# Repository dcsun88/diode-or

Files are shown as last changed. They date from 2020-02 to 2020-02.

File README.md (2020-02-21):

# diode-or
Active and Passive Diode ORing KiCAD Design

The passive or'ing is two parallel 20A 100V shcottky diodes.  The active or'ing uses a 72A 100V N-channel MOSFET and the lm5050-1 or'ing controller.  The binding posts are set up so both paths can be used in parallel or independently.

## Mechanical parts not in the BOM
* 1  Hammond Manufacturing  1591L  box 3.30"Lx2.20"Wx1.40"H
* 4x M3x5mm pan head Phillips screw
* 2x Wakefield-Vette  CD-02-05-247 Or CD-02-05-247-N  TO-247 ulTIMiFlux Dielectric Phase Change Thermal Material
* 1  Pomona  4115  Binding post shorting link
* 5x Binding post connector assembly.
   * 5x TE Connectivity  326854  terminal, ring 14-16AWG  #2 stud
   * 5x TE Connectivity  34123  terminal, ring 14-16AWG  #10 stud
   * 5x McMaster-Carr 69925K67  grounding braid noninsulated, 14 wire gauge equivalent, 20mm length

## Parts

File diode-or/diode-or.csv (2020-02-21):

Reference | Value | Footprint | Datasheet | Manufacturer | PartNum | Power | Tolerance | Dielectric | Voltage | Current
R1 | 100R | local:R_0805_HandSoldering |  | Vishay Dale | CRCW0805100RFKEA | 0.125W | 1%
U1 | LM5050-1 | Package_TO_SOT_SMD:TSOT-23-6 | http://www.ti.com/lit/ds/symlink/lm5050-1-q1.pdf | Texas Instruments | LM5050MKX-1
C2 | 0.1uF | local:C_0805_HandSoldering |  | Kemet | C0805C104K5RACTU |  | 10% | X7R | 50V
D1 | STPS40H100CW | Package_TO_SOT_THT:TO-247-3_Vertical | ~ | STMicro | STPS40H100CW |  |  |  | 100V | 20A
D3 | LL4148 | local:D_MiniMELF-onsemi |  | ON Semiconductor | LL4148 |  |  |  | 100V | 200mA
J1 | Binding Post (RED) | local:Binding_Post_Hex | ~ | Keystone | 7016
J3 | Binding Post (RED) | local:Binding_Post_Hex | ~ | Keystone | 7016
J4 | Binding Post (BLACK) | local:Binding_Post_Hex | ~ | Keystone | 7017
D4 | SS16T3 | Diode_SMD:D_SMA | ~ | ON Semiconductor | SS16T3 |  |  |  | 60V | 1A
D6 | SS16T3 | Diode_SMD:D_SMA | ~ | ON Semiconductor | SS16T3 |  |  |  | 60V | 1A
D2 | SMBJ60A | Diode_SMD:D_SMB | ~ | Littelfuse | SMBJ60A | 5.0W |  |  | 60V
J2 | Binding Post (RED) | local:Binding_Post_Hex | ~ | Keystone | 7016
J5 | Binding Post (BLACK) | local:Binding_Post_Hex | ~ | Keystone | 7017
R2 | 100R | local:R_0805_HandSoldering |  | Vishay Dale | CRCW0805100RFKEA | 0.125W | 1%
D5 | LL4148 | local:D_MiniMELF-onsemi |  | ON Semiconductor | LL4148 |  |  |  | 100V | 200mA
SW1 | SW_SPDT | local:ASE1D-6M-10-Z | ~ | Nidec Copal | ASE1D-2M-10-Z |  |  |  | 60V | 50mA
C3 | 1uF | local:C_1206_HandSoldering |  | Samsung | CL31B105KCHNFNE |  | 10% | X7R | 100V
C1 | 22uF | Capacitor_SMD:CP_Elec_6.3x5.9 |  | Panasonic | EEE-FK1J220XP |  | 20% | Alum | 63V
BT1 | Battery | Connector_PinHeader_2.54mm:PinHeader_1x02_P2.54mm_Vertical | ~ |  |  |  |  |  | 9.0V
Q1 | IRFP4710PBF | Package_TO_SOT_THT:TO-247-3_Vertical | ~ | Infineon | IRFP4710PBF | 190W |  |  | 100V | 72A
D8 | AM2520ZGC09 | local:AM2520ZGC09 | ~ | Kingbright | AM2520ZGC09
D7 | MM3Z3V0T1G | local:SOD-323_477-02-H_HandSoldering | ~ | ON Semiconductor | MM3Z3V0T1G | 300mW |  |  | 3.0V
R3 | 4.99K | local:R_0805_HandSoldering |  | Vishay Dale | CRCW08054K99FKEA | 0.125W | 1%
H1 | MountingHole_Pad | MountingHole:MountingHole_3.2mm_M3_Pad_Via | ~
H3 | MountingHole_Pad | MountingHole:MountingHole_3.2mm_M3_Pad_Via | ~
H2 | MountingHole_Pad | MountingHole:MountingHole_3.2mm_M3_Pad_Via | ~
H4 | MountingHole_Pad | MountingHole:MountingHole_3.2mm_M3_Pad_Via | ~
HS1 | MA-301-27E | local:MA-301-27E | ~ | Ohmite | MA-301-27E
U2 | PSSI2021SAY | Package_TO_SOT_SMD:SOT-353_SC-70-5 | ~ | NXP Semiconductors | PSSI2021SAY

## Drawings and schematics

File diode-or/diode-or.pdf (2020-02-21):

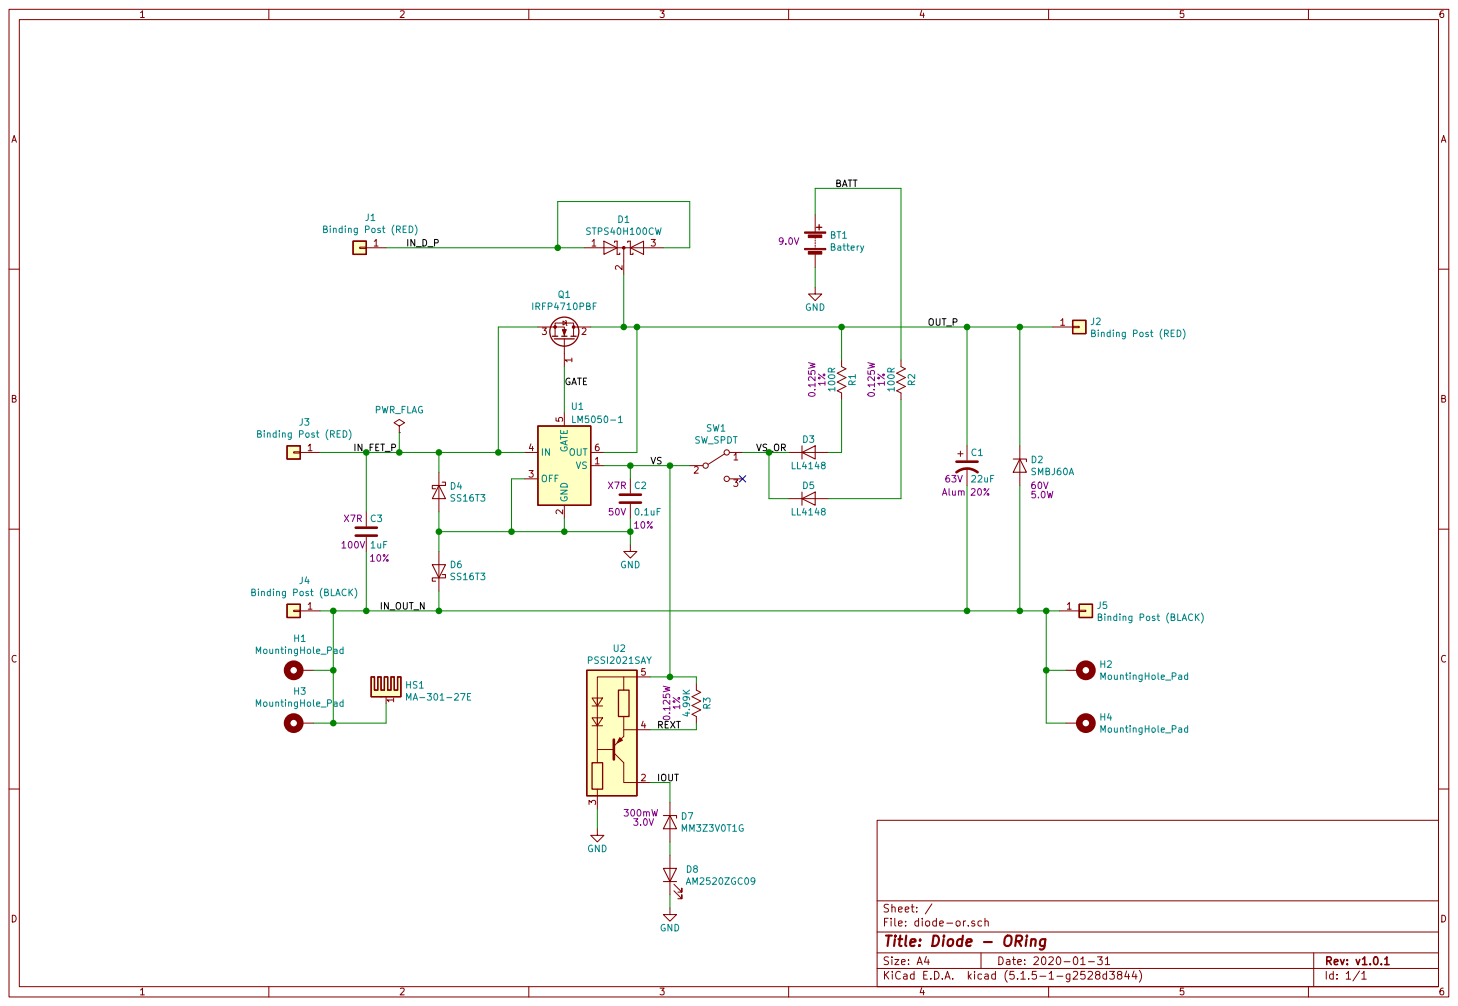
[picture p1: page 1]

File: diode-or.sch Sheet: /
Id: 1/1 Title: Diode - ORing

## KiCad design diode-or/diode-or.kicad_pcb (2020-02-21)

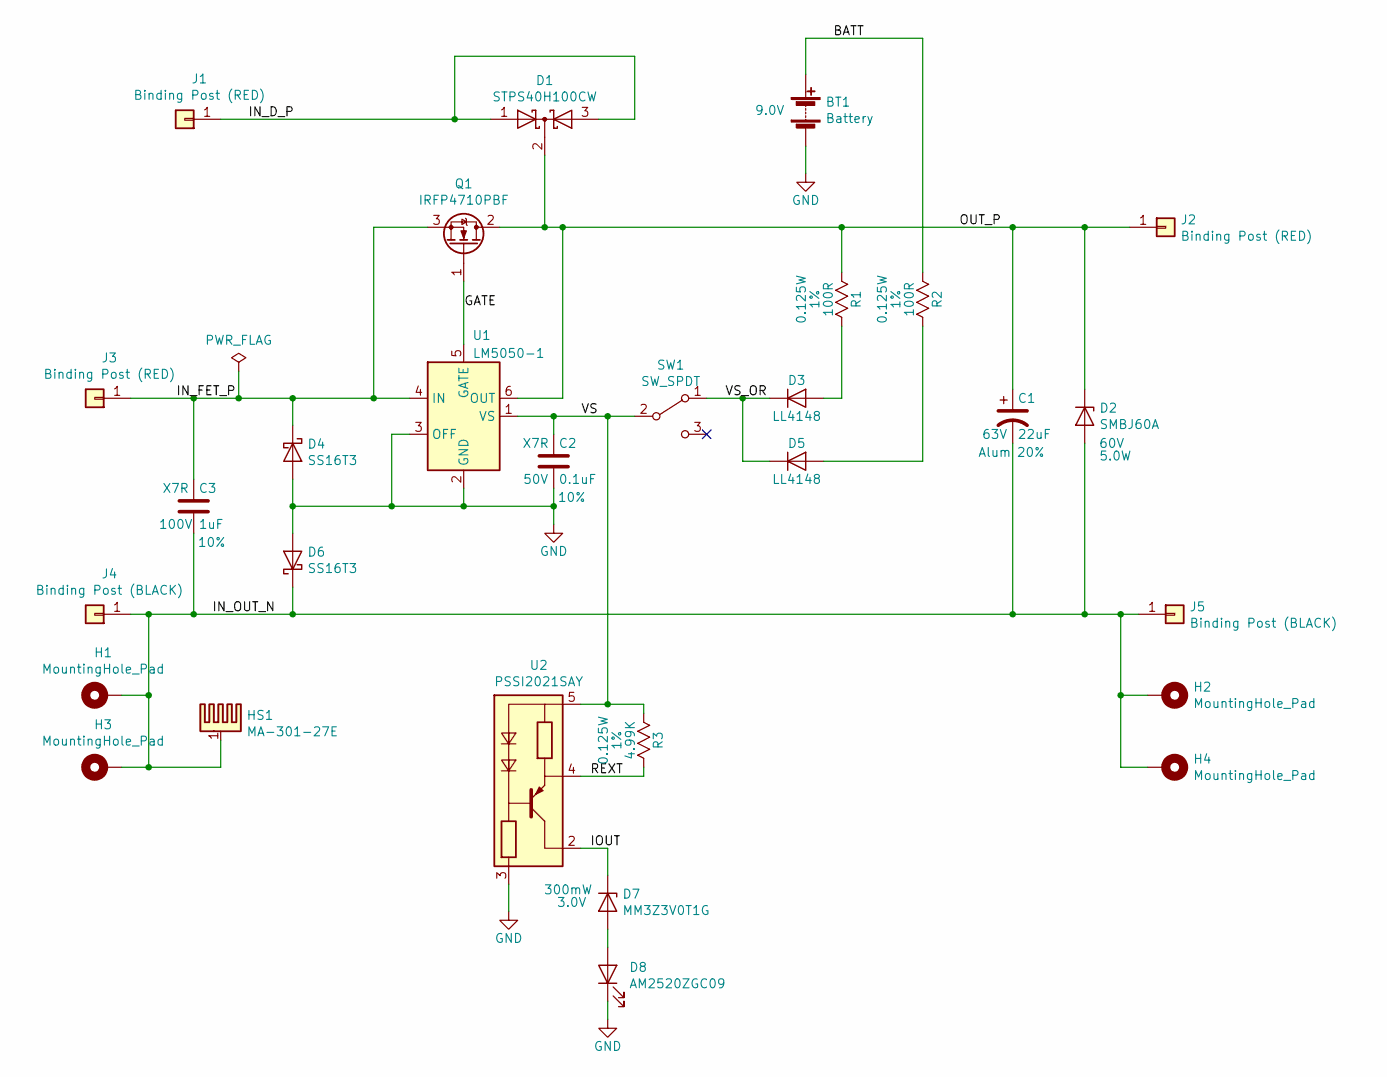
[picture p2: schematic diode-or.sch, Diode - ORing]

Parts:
BT1: Battery; PinHeader_1x02_P2.54mm_Vertical; Voltage 9.0V
C1: 22uF; CP_Elec_6.3x5.9; Voltage 63V; Tolerance 20%; PartNum EEE-FK1J220XP
C2: 0.1uF; C_0805_HandSoldering; Voltage 50V; Tolerance 10%; PartNum C0805C104K5RACTU
C3: 1uF; C_1206_HandSoldering; Voltage 100V; Tolerance 10%; PartNum CL31B105KCHNFNE
D1: STPS40H100CW; TO-247-3_Vertical; Voltage 100V; PartNum STPS40H100CW
D2: SMBJ60A; D_SMB; Voltage 60V; PartNum SMBJ60A
D3, D5: LL4148; D_MiniMELF-onsemi; Voltage 100V; PartNum LL4148
D4, D6: SS16T3; D_SMA; Voltage 60V; PartNum SS16T3
D7: MM3Z3V0T1G; SOD-323_477-02-H_HandSoldering; Voltage 3.0V; PartNum MM3Z3V0T1G
D8: AM2520ZGC09; PartNum AM2520ZGC09
H1, H2, H3, H4: MountingHole_Pad; MountingHole_3.2mm_M3_Pad_Via
HS1: MA-301-27E; PartNum MA-301-27E
J1, J2, J3: Binding Post (RED); Binding_Post_Hex; PartNum 7016
J4, J5: Binding Post (BLACK); Binding_Post_Hex; PartNum 7017
Q1: IRFP4710PBF; TO-247-3_Vertical; Voltage 100V; PartNum IRFP4710PBF
R1, R2: 100R; R_0805_HandSoldering; Tolerance 1%; PartNum CRCW0805100RFKEA
R3: 4.99K; R_0805_HandSoldering; Tolerance 1%; PartNum CRCW08054K99FKEA
SW1: SW_SPDT; ASE1D-6M-10-Z; Voltage 60V; PartNum ASE1D-2M-10-Z
U1: LM5050-1; TSOT-23-6; PartNum LM5050MKX-1
U2: PSSI2021SAY; SOT-353_SC-70-5; PartNum PSSI2021SAY

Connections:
/BATT: BT1.1 (+), R2.1
/GATE: Q1.1 (G), U1.5 (GATE)
/IN_D_P: D1.1 (A), D1.3 (A), J1.1
/IN_FET_P: C3.1, D4.1 (K), J3.1, Q1.3 (S), U1.4 (IN)
/IN_OUT_N: C1.2, C3.2, D2.2 (A), D6.1 (K), H1.1, H2.1, H3.1, H4.1, HS1.1, J4.1, J5.1
/IOUT: D7.1 (K), U2.2 (IOUT)
/OUT_P: C1.1, D1.2 (K), D2.1 (K), J2.1, Q1.2 (D), R1.1, U1.6 (OUT)
/REXT: R3.2, U2.4 (REXT)
/VS: C2.1, R3.1, SW1.2 (B), U1.1 (VS), U2.5 (VS)
/VS_OR: D3.1 (K), D5.1 (K), SW1.1 (A)
GND: BT1.2 (-), C2.2, D4.2 (A), D6.2 (A), D8.1 (K), U1.2 (GND), U1.3 (OFF), U2.3 (GND)
unnamed: D3.2 (A), R1.2
unnamed: D5.2 (A), R2.2
unnamed: D7.2 (A), D8.2 (A)

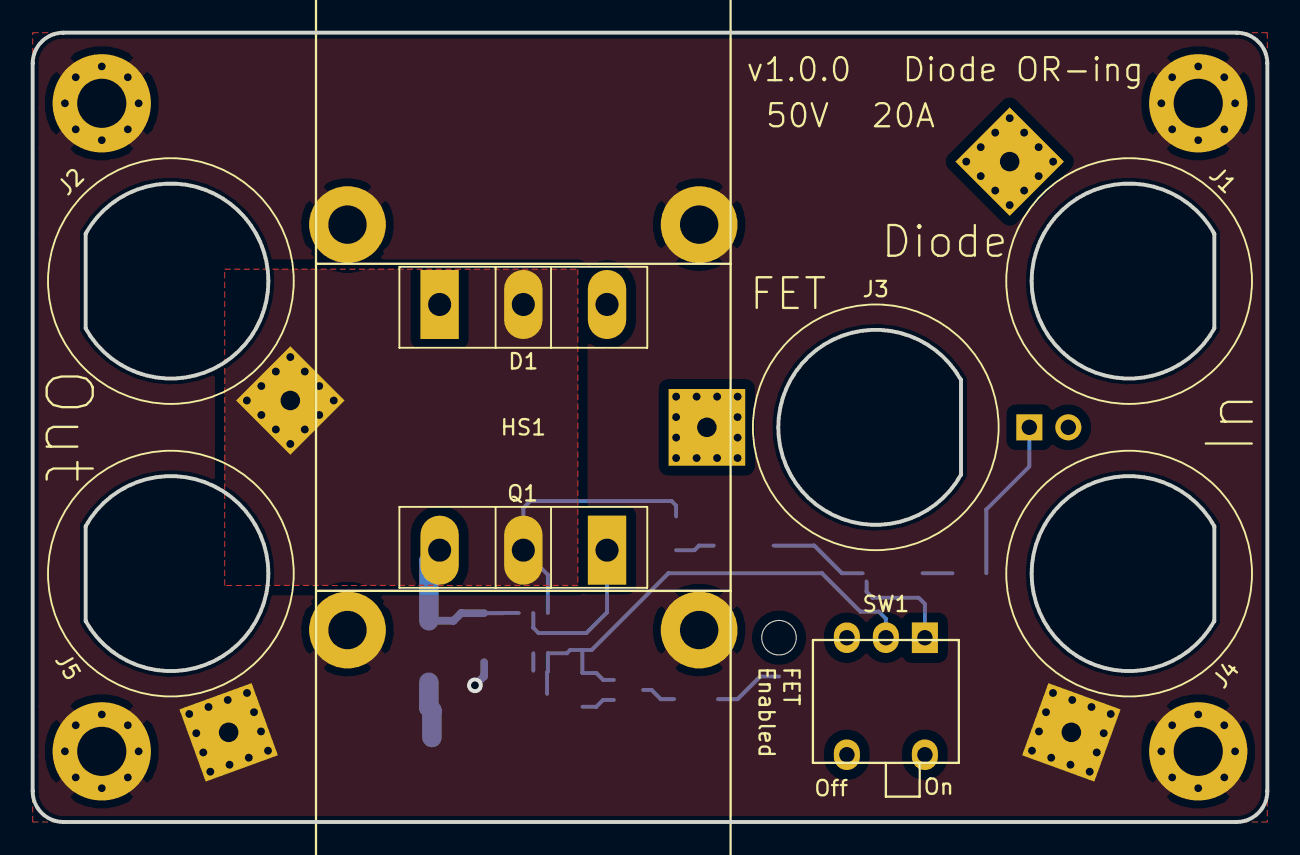
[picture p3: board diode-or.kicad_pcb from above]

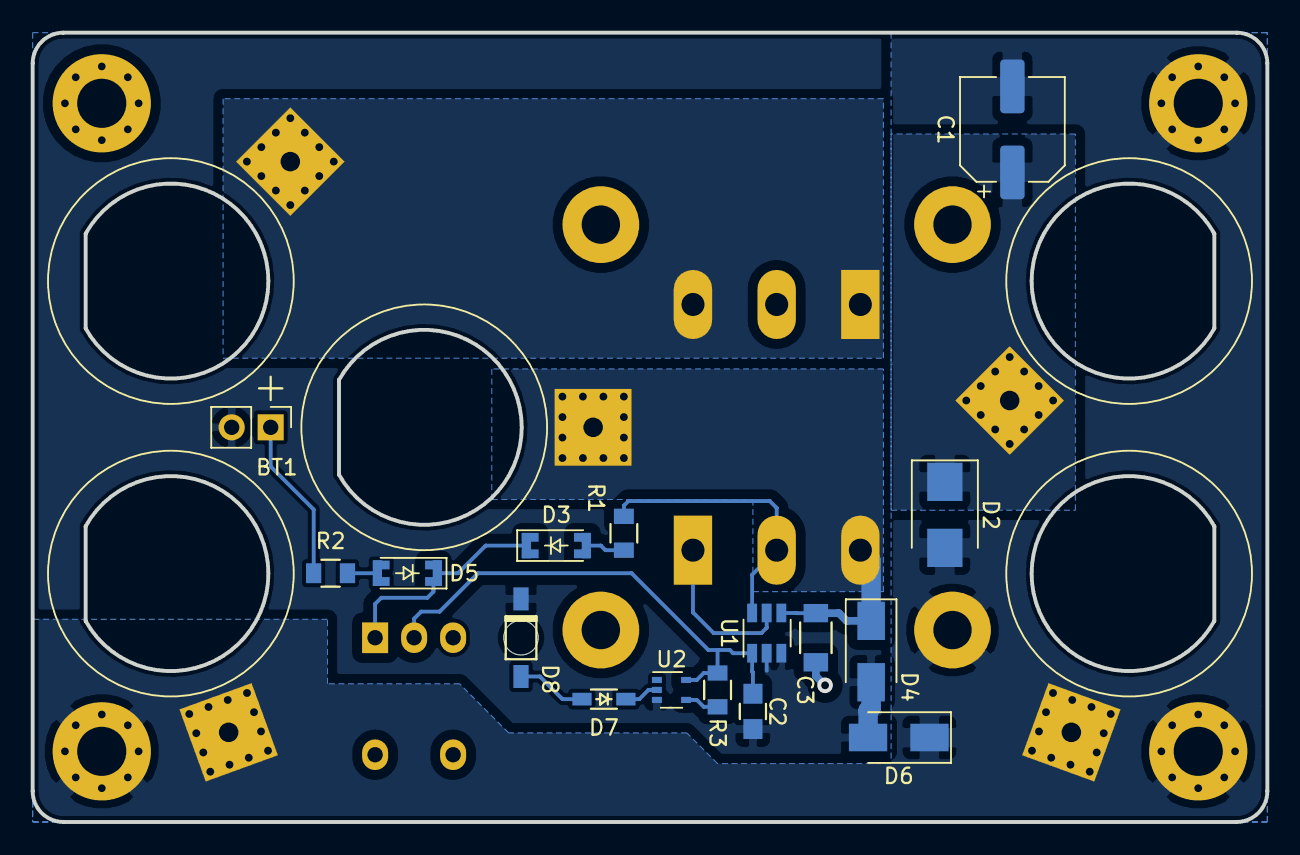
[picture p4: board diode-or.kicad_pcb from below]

Board: 2 copper layers, 80.4 x 51.4 mm, 29 parts (16 on the bottom side), 14 nets.

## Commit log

2020-02-05 Snapshot diode-or design.
    [diode-or.kicad_pcb, diode-or.sch]
2020-02-05 Routed diode-or board. Add generated files.
    [diode-or.csv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]
2020-02-05 Changes to courtyard and pad connection settings.
    [diode-or.kicad_pcb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]
2020-02-05 Update the binding post footprint on the diode-or board.
    [diode-or.kicad_pcb]
2020-02-05 Use a current source to drive the LED indicator. Update footprints in the diode-or board.
    [diode-or.csv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]
2020-02-05 Fix resistor part number. Clean up position of text on the Fab layers.
    [diode-or.csv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]
2020-02-05 Minor change to fill zones. Upload to OSHPark.
    [diode-or.csv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]
2020-02-21 Change current source resistor value to 4.99k
    [diode-or.csv, diode-or.kicad_pcb, diode-or.sch]
